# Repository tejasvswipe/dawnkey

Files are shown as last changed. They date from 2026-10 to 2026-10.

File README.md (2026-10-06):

# DAWNKEY — BLARE alarm clock

A custom BLARE alarm clock with a 12-key MX keypad, TFT display, DS3231 real-time clock, two-AA battery input and a distinctive printable case. The enclosure preview uses a black battery pod, dark display bezel and black **“for tejas”** lettering.
# gallery
preview_overall


## Deliverables

- **PCB source:** `PCB/DawnKey.kicad_pro`, routed `PCB/DawnKey.kicad_pcb`, placement-only backup, reproducible generator and the full BOM.
- **Fabrication:** `Production/Gerbers.zip` with copper, mask, silkscreen, board outline and separate plated/non-plated drill files; `Production/placements.csv` for assembly.
- **Enclosure:** OpenSCAD source, print-ready STLs and per-part/assembly STEP files under `CAD/`.
- **Firmware:** Arduino sketch and the key-by-key guide under `Firmware/`.
- **Build docs:** [power, wiring and button guide](Docs/Power_and_IO.md), [system block diagram](Docs/System_Architecture.png), sources, preview and preflight report.
 handoff, not a board ready to order or rely on as an alarm clock; complete full KiCad DRC, resolve the router discrepancy, inspect the boost layout and bench-test the assembled device first. The exact checks are in [`Production/Preflight.md`](Production/Preflight.md).

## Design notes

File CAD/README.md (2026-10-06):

# DAWNKEY case and print files

The case is a **parametric prototype** for the 94 × 90 mm PCB. The concept combines a dark raised TFT visor, 4 × 3 MX switch plate, buzzer vents, neon-style accent slots, a serviceable side battery pod and the black **“for tejas”** name insert.

## Files

- `DAWNKEY_Case.scad` — editable OpenSCAD master; change its `part` variable to render `base`, `top`, `bezel`, `battery_pod`, `battery_door`, `accents`, `text`, `key_labels` or the concept assembly.
- `STL/` — individual print-ready meshes; `key_labels.stl` and `text.stl` can be printed in black or inserted as separate color parts.
- `STEP/DAWNKEY_Case_Assembly.step` — positioned faceted case assembly; individual STEP files are alongside it. The STEP shapes were converted from STL meshes, so they are faceted rather than native analytic CAD solids.
- `STEP/DawnKey_PCB.step` — board-only STEP export.
- `stl_to_step.FCMacro` — reproducible FreeCAD STL-to-STEP export macro.

## Prototype geometry

The base/plate envelope is 108 × 132 mm. The side AA pod cavity is nominally 66 × 37 × 19 mm. The top plate has four M3 clearance openings, twelve nominal 14 mm MX apertures on 19.05 mm pitch, an ST7789 viewing aperture and a vent pattern over the piezo. The case is designed around common-size components; no actual TFT, AA holder, switch or heat-set insert has been test-fitted.

## Suggested assembly and print workflow

1. Render a small test of one MX opening, one M3 post and the display/bezel interface before printing all parts.
2. Print the base, top plate, visor, battery pod and door as separate pieces. Use the accent, wordmark and key-label meshes for a second color; the intended look is a light shell with black lettering/trim and a dark battery pod/visor.
3. Test the purchased 2-AA holder in the pod and measure its switch/harness. Adjust `DAWNKEY_Case.scad` if its actual dimensions differ from the nominal cavity.
4. Fit the TFT with the real panel PCB/cable; confirm the USB-C access slot and all four M3 inserts before final assembly.
5. Only then use the print-ready files for a full case.

The case render is a design visualization, **not proof of fit**. Check tolerances against your printer, filament shrinkage and actual parts.

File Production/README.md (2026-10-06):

# PCB production outputs

`Gerbers.zip` is the standard two-layer fabrication package. It contains the front/back copper, solder-mask and silkscreen layers, the Edge.Cuts outline, the Excellon plated (`PTH`) and non-plated (`NPTH`) drill files, KiCad’s Gerber job file, and SVG drill maps. Drill coordinates are in millimeters with absolute origin.

`placements.csv` is the component placement export for assembly. `pad_net_map.csv` is the component pad/net reference for review.

The board outline is nominally 94 × 90 mm with four M3-clearance holes. Before placing a manufacturing order, inspect the archive in the chosen fab’s Gerber viewer and confirm the material/thickness, copper weight, finish, tolerances, drill registration, and component clearances with that fab. The design has not been fabricated or electrically bench-tested; see `Preflight.md`. The native KiCad DRC is still required before manufacture.

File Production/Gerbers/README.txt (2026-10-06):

DAWNKEY PCB fabrication outputs

Board: nominal 94 x 90 mm, two copper layers.
Copper: DawnKey-F_Cu.gtl (front), DawnKey-B_Cu.gbl (back).
Mask: DawnKey-F_Mask.gts (front), DawnKey-B_Mask.gbs (back).
Silkscreen: DawnKey-F_Silkscreen.gto (front), DawnKey-B_Silkscreen.gbo (back).
Outline: DawnKey-Edge_Cuts.gm1.
Drills: DawnKey-PTH.drl (plated) and DawnKey-NPTH.drl (non-plated), Excellon, millimeters, absolute origin.

Review every layer and drill file in the board house's Gerber viewer before ordering. Material, copper weight, finish and tolerances are not prescribed here. See the project-level Production/Preflight.md: the design remains a prototype pending full KiCad DRC and resolution of a KiCad/FreeRouting round-trip discrepancy.

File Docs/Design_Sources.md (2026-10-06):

# Design sources and constraints

- BLARE Getting Started: https://blare.hackclub.com/docs/getting-started — kit includes XIAO ESP32-C3, 12 MX switches/keycaps, 12 1N4148 diodes, 2.25-inch TFT, 3.3 V piezo, display header/jumpers, and M3 case hardware.
- BLARE PCB guide: https://blare.hackclub.com/docs/pcb-design — KiCad `.kicad_pro`, `.kicad_sch`, `.kicad_pcb`, Gerber/Drill ZIP, and PCB STEP export; board under 100 mm per side.
- BLARE CAD guide: https://blare.hackclub.com/docs/cad — complete assembled STEP; separate case parts STEP or STL; switch, screen, USB and buzzer openings; M3 inserts/posts; leave at least 0.2 mm fit tolerance.
- BLARE submission guide: https://blare.hackclub.com/docs/submitting-your-project — folders `CAD`, `PCB`, `Firmware`, `Production`; `Production/gerbers.zip`; README screenshots for overall build, schematic, PCB, and case fit, plus BOM; DRC should show zero errors.
- BLARE firmware guide: https://blare.hackclub.com/docs/firmware — ST7789 panel is 76×284; display can use the documented XIAO GPIO mapping; active-low backlight.
- Seeed XIAO ESP32-C3 official hardware guide: https://wiki.seeedstudio.com/XIAO_ESP32C3_Getting_Started/ — 5V/VBUS is a power input/output; external supply must feed it through a diode with anode at source and cathode at XIAO 5V. The 3V3 pin is regulator output, not the battery input. Seeed documents 3.7 V lithium-battery input, not direct 2×AA input.
- Texas Instruments TPS61023 datasheet: https://www.ti.com/lit/ds/symlink/tps61023.pdf — 0.5–5.5 V operating input; 1.8 V minimum startup; 2.2–5.5 V output; typical 5 V/1.5 A design is specified at 2.7–4.35 V input. For 2×AA, output current must be validated at depleted-cell voltage and actual clock load; do not assume 1.5 A at 1.8 V.
- TI TPS61022/TPS61023 layout guidelines: https://www.ti.com/lit/pdf/slvaes4 — keep the switching/current loop and output capacitors tight; route feedback away from noisy SW node.

## Battery safety/design note

A two-cell AA series pack spans roughly 1.8 V at end-of-life to about 3.3 V fresh (cell chemistry dependent). A regulated boost stage is required for the XIAO 5V pin; use an output isolation Schottky diode per Seeed. There is no onboard AA charging. Do not place raw AA voltage on XIAO 3V3 or 5V. Wi-Fi, bright TFT backlight, and buzzer duty cycle determine battery life; measure on the finished firmware/load before quoting runtime.

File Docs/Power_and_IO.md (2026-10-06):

# DAWNKEY power, wiring and controls

## 1. Two-AA power path

Use a **two-cell AA holder wired in series** with a 2-pin JST-PH lead. The PCB connector is `J3`:

| J3 pin | PCB net | Connect to |
|---|---|---|
| 1 | `BAT_RAW` | Positive from the battery holder, through an inline SPST on/off switch |
| 2 | `GND` | Battery-holder negative |

The board uses a **TPS61023 boost converter** to make a regulated nominal 5 V rail (`BOOST_5V`). Its output reaches the Seeed XIAO ESP32-C3 5V pad through **D13, an SS14 Schottky diode**. The diode is oriented with its anode at `BOOST_5V` and cathode at `USB_5V` / the XIAO 5V pad. The XIAO’s onboard regulator then supplies the 3.3 V rail used by the RTC, GPIO expander, display logic and buzzer.

**Important:** raw AA voltage must never be connected directly to the XIAO 3V3 pin or directly to its 5V pin. The cells are primary power sources; the PCB does **not** charge NiMH cells. Use a matched pair of the same chemistry and state of charge. Before inserting cells, check polarity, inspect U4/L1/D13 orientation, and measure the boosted output and the diode-side XIAO input with a current-limited bench supply. Test USB-versus-battery behavior on the bench; do not assume it is safe until verified on the assembled board.

The DS3231 `VBAT` pin is tied to ground because the AA pack is intended to remain the clock’s always-on supply. **If the AA pack is removed, the RTC time will be lost** (the firmware initializes the date/time from its compile timestamp at next start). This design has no separate coin-cell backup.

## 2. Signal and connector map

### XIAO ESP32-C3

| XIAO Arduino pin | Role | Routed net |
|---|---|---|
| D0 | TFT SCLK | `TFT_SCLK` |
| D1 | TFT MOSI | `TFT_MOSI` |
| D2 | TFT reset | `TFT_RST` |
| D3 | TFT data/command | `TFT_DC` |
| D4 | TFT chip select | `TFT_CS` |
| D5 | TFT backlight enable | `TFT_BL` (active-low on the BLARE panel) |
| D6 | I²C clock | `I2C_SCL` |
| D7 | I²C data | `I2C_SDA` |
| D10 | Piezo driver control | `BUZZER_CTL` |
| 5V | Boost/USB input | `USB_5V` through D13 from battery boost |
| 3V3 | Regulated output | `3V3` |
| GND | Common return | `GND` |

GPIO8/GPIO9 are deliberately left unused because of ESP32-C3 boot-strapping considerations.

### TFT header J1

The 8-pin BLARE/ST7789 header order is **GND, 3V3, SCLK, MOSI, RST, DC, CS, BL**. The display is an external module connected with the kit jumper wires; it is not soldered flat to the PCB.

### I²C devices and expansion J2

- U2 MCP23017: address `0x20`; GPIO expander for the keypad.
- U3 DS3231: address `0x68`; clock/alarm time source.
- Pull-ups R4/R5: 4.7 kΩ from SDA/SCL to 3V3.
- J2 pins 1–4: **3V3, GND, SDA, SCL**. This is a low-current sensor/accessory header, not a general-purpose power output.

R3–R5 are non-polar 0603 resistors. Their PCB pad numbering is intentionally exchanged to compensate for the underside autorouter/import transform; electrically, each resistor still connects the signal named in the BOM to 3V3. There is no physical resistor polarity or orientation requirement.

### Key matrix

U2 GPA0–GPA3 are columns 0–3; GPA4–GPA6 are rows 0–2. One 1N4148 diode is fitted per MX-style switch to prevent matrix ghosting. The diode direction is from each row toward its switch/column node as shown by the PCB net assignments.

## 3. Every button

Viewed from the front with the display above the keypad, read left-to-right and top-to-bottom:

| Position / label | Normal clock screen | While setting time/alarm | While ringing |
|---|---|---|---|
| Top row: `1`, `2`, `3`, `4` | No action | Enters that digit | Enters that digit into the dismiss code |
| Middle row: `5`, `6`, `7`, `8` | No action | Enters that digit | Enters that digit into the dismiss code |
| Bottom-left: `9` | No action | Enters 9 | Enters 9 into the dismiss code |
| Bottom, second: `0` | No action | Enters 0 | Enters 0 into the dismiss code |
| Bottom, third: `S` / Snooze (SW11) | Short press changes the display page; hold about 0.85 s to set the RTC clock | Short press clears the typed entry | Short press silences the buzzer and snoozes for 5 minutes |
| Bottom-right: `OK` / Stop (SW12) | Short press toggles the alarm on/off; hold about 0.85 s to set the alarm time | Saves a valid four-digit `HHMM` value | Stops only after the four-digit code is entered and confirmed |

The starter firmware’s example dismiss code is **3141**. While ringing, type the four digits with keys 1–0 and press `OK`. A wrong code clears the entry but leaves the alarm active. The default alarm is **07:00 and enabled**. In either setting mode, enter 24-hour `HHMM` using the number keys; invalid hour/minute values are rejected.

## 4. Bring-up checklist

1. Assemble the board without batteries. Inspect solder bridges, polarity, connector pin order, U4, L1 and D13.
2. Power through a current-limited bench supply at J3. Confirm the boost and diode-side rail before attaching the XIAO or display.
3. Scan I²C: expect MCP23017 `0x20` and DS3231 `0x68`.
4. Verify the display pin order/backlight polarity and test every matrix key individually.
5. Confirm buzzer switching, RTC time setting, alarm setting, snooze, wake-code dismissal, and both USB/battery source modes.
6. Measure battery current and runtime with the actual TFT backlight and alarm duty cycle. Runtime has not yet been measured; the starter sketch keeps the backlight on.

This is a prototype package. No physical board has been fabricated or bench-tested here; inspect the KiCad DRC report and verify current, voltage, thermal behavior and mechanical fit before relying on it as a daily alarm.

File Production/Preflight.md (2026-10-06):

# Release preflight and limits

## Checks performed on this release

- **KiCad native connectivity API:** the imported `PCB/DawnKey.kicad_pcb` reports **0 unconnected connections** (`GetUnconnectedCount(True) = 0`).
- **FreeRouting 2.5 on the placement-only KiCad export:** `PCB/route.log` reports **0 unrouted connections and 0 clearance violations** (score 1000/1000). `PCB/DawnKey.ses` is the resulting routing session.
- **Gerber/drill/position exports:** produced with KiCad CLI 7 from the routed board; PTH and NPTH drills are separate, in mm, absolute origin.
- **Case CAD:** OpenSCAD produced the STL parts; FreeCAD reported all eight meshes as valid and exported the individual and positioned assembly STEP files.

## Important unresolved discrepancy

I also exported a fresh Specctra DSN from the **imported final `.kicad_pcb`** and re-ran FreeRouting on that round-tripped board. KiCad still reported 0 unconnected connections, but FreeRouting reported **5 unrouted items and 0 clearance violations**. This disagreement is not resolved. The placement-board router result and the KiCad connectivity graph are encouraging, but they do not prove that every imported copper endpoint is interpreted identically by both tools.

## Required before fabrication or daily use

1. Open the final project in a current KiCad version, run the full native **DRC**, inspect the ratsnest and inspect the buzzer, underside pull-ups, battery boost and display connections.
2. Review the Gerbers in the intended board house’s viewer.
3. Verify the actual TFT, 2-AA holder, MX switches, heat-set inserts and case clearances with physical components; the enclosure has not been test-fitted.
4. The Arduino toolchain/libraries were not available here, so the firmware was **not compiled or uploaded**. Compile for the Seeed XIAO ESP32-C3 and test every mode before assembly use.
5. No physical PCB has been fabricated or bench-tested. Check the 5 V/3.3 V rails with a current-limited supply before installing cells; do not rely on this prototype as a tested alarm clock yet.

The installed KiCad 7 command-line interface does not provide `kicad-cli pcb drc`; therefore no full KiCad DRC result is claimed. Treat this package as a complete design handoff/prototype, **not as a certified or production-released board**.

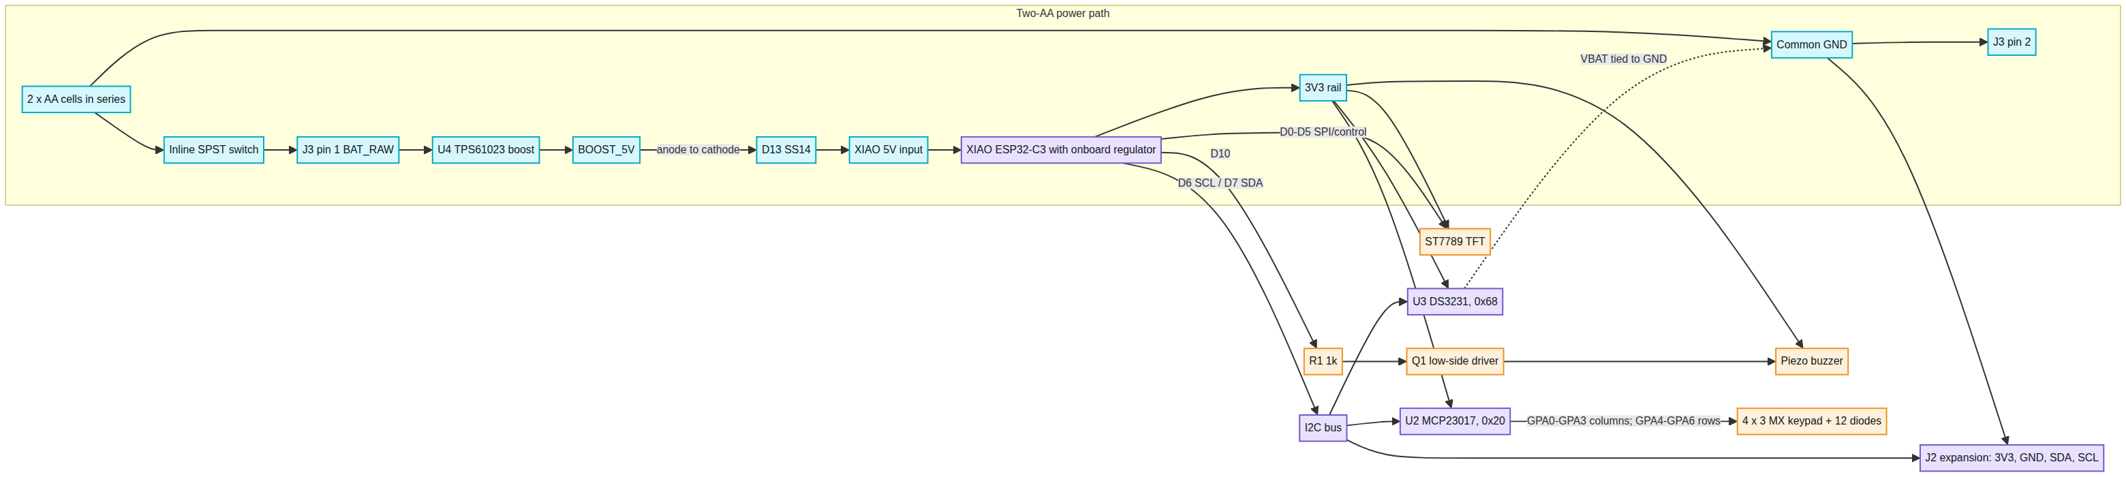
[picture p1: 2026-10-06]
Docs/System_Architecture.png

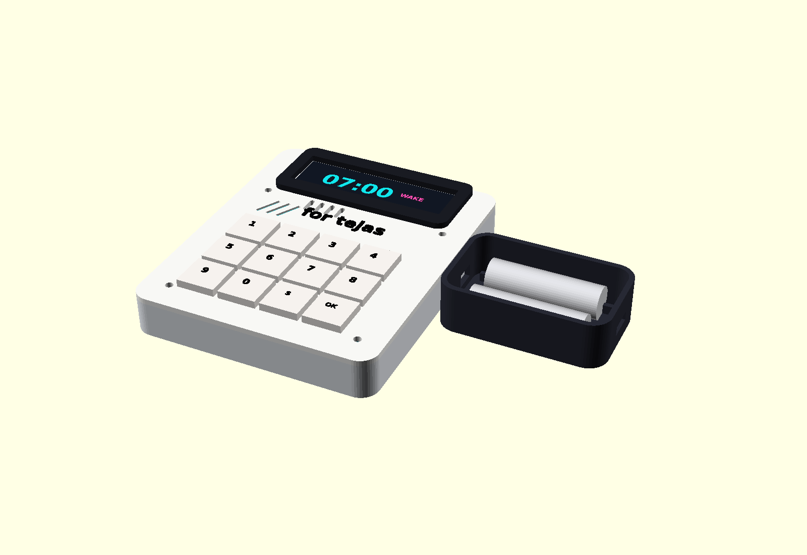
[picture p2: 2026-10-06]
Docs/preview_overall.png

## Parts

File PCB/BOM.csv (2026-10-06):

Reference | Qty | Description | Recommended part/value | Package / interface | Notes
U1 | 1 | MCU module | Seeed XIAO ESP32-C3 | Module | Kit part; mount on underside per board footprint
U2 | 1 | I2C GPIO expander | MCP23017-I/SO | SOIC-28W | Address 0x20; keypad matrix
U3 | 1 | RTC | DS3231S | SOIC-16W | Address 0x68; unused VBAT tied to GND
U4 | 1 | AA boost converter | TI TPS61023DRLR or equivalent TPS61023 SOT-563 | 6-pin SOT-563 | Check exact package variant/pin-1 mark against datasheet
L1 | 1 | Boost inductor | Würth 74438357010 1uH | 4.1x4.1mm shielded | Select >=7A saturation current; follow TI layout guidance
D13 | 1 | 5V isolation diode | SS14 Schottky | DO-214AC / SMA | Pad 2 anode=boost; pad 1 cathode=XIAO 5V
C3 | 1 | Boost input capacitor | 10uF 10V X7R | 0805 | Place tight to U4 VIN/GND
C4 | 1 | High-frequency input bypass | 100nF X7R | 0603 | Place tight to U4 VIN/GND
C5-C6 | 2 | Boost output capacitors | 22uF 10V X7R | 0805 | Parallel; check effective capacitance under DC bias
R6 | 1 | Feedback upper resistor | 732k 1% | 0603 | BOOST_5V to FB
R7 | 1 | Feedback lower resistor | 100k 1% | 0603 | FB to GND
DISP1 | 1 | Display module | 2.25in ST7789 76x284 panel | 8-pin jumper cable | Kit item; VCC=3V3; BL active-low
J1 | 1 | TFT connector | 1x8 2.54mm pin header | Through-hole | BLARE kit order: GND | 3V3 | SCLK | MOSI | RST | DC | CS | BL
J2 | 1 | I2C expansion | 1x4 2.54mm header | Through-hole | 3V3/GND/SDA/SCL
J3 | 1 | 2-cell battery input | JST-PH 2-pin 2.0mm | Side-entry connector | Two AA in series; switched battery-positive input
BT1 | 1 | AA holder | 2-cell AA series holder with JST-PH lead | External case pocket | Alkaline or NiMH pair; no charging circuit on PCB
SW-PWR | 1 | Power switch | SPST slide switch rated >=1A | Inline on AA positive lead | Panel slot in battery pod; confirm switch body dimensions
SW01-SW12 | 12 | MX-style mechanical switches | BLARE kit switches | Plate-mount | 4 columns x 3 rows; 19.05mm pitch
D01-D12 | 12 | Signal diodes | 1N4148 | DO-35 axial | One per key; matrix direction per PCB
BZ1 | 1 | Piezo buzzer | 3.3V piezo | 12mm / 7.6mm lead pitch | Kit item; driven by Q1
Q1 | 1 | Buzzer NPN transistor | MMBT3904 | SOT-23 | Low-side switch; confirm package pinout
R1 | 1 | Buzzer base resistor | 1k | 0603 | GPIO-to-base
R2 | 1 | RTC interrupt pull-up | 10k | 0603 | RTC_INT net currently unused by starter code
R3 | 1 | MCP reset pull-up | 10k | 0603 | RESET to 3V3
R4-R5 | 2 | I2C pull-ups | 4.7k | 0603 | SDA and SCL to 3V3
C1-C2 | 2 | Logic decoupling | 100nF X7R | 0603 | One each for MCP23017 and DS3231
H1-H4 | 4 | PCB mounting holes | M3 clearance | 3.2mm NPTH | Match case supports/heat-set inserts
CASE | 1 | Enclosure set | Top plate | bottom shell | display bezel | battery pod and door | 3D printed | See CAD folder; verify exact display/holder and switch sizes before printing

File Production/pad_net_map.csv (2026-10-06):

Reference | Value | Pad | Net | X_mm | Y_mm | Side
BZ1 | 3.3V PIEZO | 1 | 3V3 | 28.200 | 74.000 | B.Cu
BZ1 | 3.3V PIEZO | 2 | BUZZER | 35.800 | 74.000 | B.Cu
C1 | 100nF MCP DECOUPLE | 1 | 3V3 | 56.300 | 74.700 | B.Cu
C1 | 100nF MCP DECOUPLE | 2 | GND | 56.300 | 76.300 | B.Cu
C2 | 100nF RTC DECOUPLE | 1 | 3V3 | 70.500 | 70.000 | B.Cu
C2 | 100nF RTC DECOUPLE | 2 | GND | 70.500 | 71.600 | B.Cu
C3 | 10uF 10V X7R IN | 1 | BAT_RAW | 79.450 | 68.500 | B.Cu
C3 | 10uF 10V X7R IN | 2 | GND | 77.550 | 68.500 | B.Cu
C4 | 100nF BOOST HF | 1 | BAT_RAW | 77.700 | 72.000 | B.Cu
C4 | 100nF BOOST HF | 2 | GND | 79.300 | 72.000 | B.Cu
C5 | 22uF 10V X7R OUT | 1 | BOOST_5V | 87.950 | 75.500 | B.Cu
C5 | 22uF 10V X7R OUT | 2 | GND | 86.050 | 75.500 | B.Cu
C6 | 22uF 10V X7R OUT | 1 | BOOST_5V | 90.950 | 79.000 | B.Cu
C6 | 22uF 10V X7R OUT | 2 | GND | 89.050 | 79.000 | B.Cu
D01 | 1N4148 / DO-35 | 1 | KINT01 | 21.425 | 46.520 | B.Cu
D01 | 1N4148 / DO-35 | 2 | KEY_ROW0 | 29.045 | 46.520 | B.Cu
D02 | 1N4148 / DO-35 | 1 | KINT02 | 40.475 | 46.520 | B.Cu
D02 | 1N4148 / DO-35 | 2 | KEY_ROW0 | 48.095 | 46.520 | B.Cu
D03 | 1N4148 / DO-35 | 1 | KINT03 | 59.525 | 46.520 | B.Cu
D03 | 1N4148 / DO-35 | 2 | KEY_ROW0 | 67.145 | 46.520 | B.Cu
D04 | 1N4148 / DO-35 | 1 | KINT04 | 78.575 | 46.520 | B.Cu
D04 | 1N4148 / DO-35 | 2 | KEY_ROW0 | 86.195 | 46.520 | B.Cu
D05 | 1N4148 / DO-35 | 1 | KINT05 | 21.425 | 27.470 | B.Cu
D05 | 1N4148 / DO-35 | 2 | KEY_ROW1 | 29.045 | 27.470 | B.Cu
D06 | 1N4148 / DO-35 | 1 | KINT06 | 40.475 | 27.470 | B.Cu
D06 | 1N4148 / DO-35 | 2 | KEY_ROW1 | 48.095 | 27.470 | B.Cu
D07 | 1N4148 / DO-35 | 1 | KINT07 | 59.525 | 27.470 | B.Cu
D07 | 1N4148 / DO-35 | 2 | KEY_ROW1 | 67.145 | 27.470 | B.Cu
D08 | 1N4148 / DO-35 | 1 | KINT08 | 78.575 | 27.470 | B.Cu
D08 | 1N4148 / DO-35 | 2 | KEY_ROW1 | 86.195 | 27.470 | B.Cu
D09 | 1N4148 / DO-35 | 1 | KINT09 | 21.425 | 8.420 | B.Cu
D09 | 1N4148 / DO-35 | 2 | KEY_ROW2 | 29.045 | 8.420 | B.Cu
D10 | 1N4148 / DO-35 | 1 | KINT10 | 40.475 | 8.420 | B.Cu
D10 | 1N4148 / DO-35 | 2 | KEY_ROW2 | 48.095 | 8.420 | B.Cu
D11 | 1N4148 / DO-35 | 1 | KINT11 | 59.525 | 8.420 | B.Cu
D11 | 1N4148 / DO-35 | 2 | KEY_ROW2 | 67.145 | 8.420 | B.Cu
D12 | 1N4148 / DO-35 | 1 | KINT12 | 78.575 | 8.420 | B.Cu
D12 | 1N4148 / DO-35 | 2 | KEY_ROW2 | 86.195 | 8.420 | B.Cu
D13 | SS14 1A SCHOTTKY | 1 | USB_5V | 80.500 | 78.000 | B.Cu
D13 | SS14 1A SCHOTTKY | 2 | BOOST_5V | 76.500 | 78.000 | B.Cu
H1 | M3 CLEARANCE |  |  | 4.500 | 4.500 | F.Cu
H2 | M3 CLEARANCE |  |  | 89.500 | 4.500 | F.Cu
H3 | M3 CLEARANCE |  |  | 4.500 | 85.500 | F.Cu
H4 | M3 CLEARANCE |  |  | 89.500 | 85.500 | F.Cu
J1 | TFT / ST7789 | 1 | GND | 90.500 | 22.000 | F.Cu
J1 | TFT / ST7789 | 2 | 3V3 | 90.500 | 24.540 | F.Cu
J1 | TFT / ST7789 | 3 | TFT_SCLK | 90.500 | 27.080 | F.Cu
J1 | TFT / ST7789 | 4 | TFT_MOSI | 90.500 | 29.620 | F.Cu
J1 | TFT / ST7789 | 5 | TFT_RST | 90.500 | 32.160 | F.Cu
J1 | TFT / ST7789 | 6 | TFT_DC | 90.500 | 34.700 | F.Cu
J1 | TFT / ST7789 | 7 | TFT_CS | 90.500 | 37.240 | F.Cu
J1 | TFT / ST7789 | 8 | TFT_BL | 90.500 | 39.780 | F.Cu
J2 | I2C EXPANSION: 3V3 GND SDA SCL | 1 | 3V3 | 39.000 | 64.000 | B.Cu
J2 | I2C EXPANSION: 3V3 GND SDA SCL | 2 | GND | 39.000 | 66.540 | B.Cu
J2 | I2C EXPANSION: 3V3 GND SDA SCL | 3 | I2C_SDA | 39.000 | 69.080 | B.Cu
J2 | I2C EXPANSION: 3V3 GND SDA SCL | 4 | I2C_SCL | 39.000 | 71.620 | B.Cu
J3 | 2xAA PACK (SWITCHED) | 1 | BAT_RAW | 76.000 | 86.000 | B.Cu
J3 | 2xAA PACK (SWITCHED) | 2 | GND | 74.000 | 86.000 | B.Cu
L1 | 1uH Isat>=7A | 1 | BAT_RAW | 88.685 | 69.000 | B.Cu
L1 | 1uH Isat>=7A | 2 | BOOST_SW | 86.315 | 69.000 | B.Cu
Q1 | MMBT3904 / NPN | 1 | BUZZER_SW | 41.438 | 76.050 | B.Cu
Q1 | MMBT3904 / NPN | 2 | GND | 41.438 | 77.950 | B.Cu
Q1 | MMBT3904 / NPN | 3 | BUZZER | 39.562 | 77.000 | B.Cu
R1 | 1k BUZZER BASE | 1 | BUZZER_CTL | 31.200 | 65.500 | F.Cu
R1 | 1k BUZZER BASE | 2 | BUZZER_SW | 32.800 | 65.500 | F.Cu
R2 | 10k RTC INT PU | 1 | RTC_INT | 56.200 | 65.500 | B.Cu
R2 | 10k RTC INT PU | 2 | 3V3 | 57.800 | 65.500 | B.Cu
R3 | 10k MCP RESET PU | 1 | 3V3 | 51.000 | 63.700 | B.Cu
R3 | 10k MCP RESET PU | 2 | MCP_RESET | 51.000 | 65.300 | B.Cu
R4 | 4k7 I2C SDA PU | 1 | 3V3 | 59.000 | 63.700 | B.Cu
R4 | 4k7 I2C SDA PU | 2 | I2C_SDA | 59.000 | 65.300 | B.Cu
R5 | 4k7 I2C SCL PU | 1 | 3V3 | 64.000 | 63.700 | B.Cu
R5 | 4k7 I2C SCL PU | 2 | I2C_SCL | 64.000 | 65.300 | B.Cu
R6 | 732k BOOST FB TOP | 1 | BOOST_5V | 83.200 | 82.000 | B.Cu
R6 | 732k BOOST FB TOP | 2 | BOOST_FB | 84.800 | 82.000 | B.Cu
R7 | 100k BOOST FB BOT | 1 | BOOST_FB | 86.700 | 82.000 | B.Cu
R7 | 100k BOOST FB BOT | 2 | GND | 88.300 | 82.000 | B.Cu
SW01 | MX-STYLE KEY 01 | 1 | KEY_COL0 | 12.615 | 49.060 | F.Cu
SW01 | MX-STYLE KEY 01 | 2 | KINT01 | 18.965 | 46.520 | F.Cu
SW01 | MX-STYLE KEY 01 |  |  | 11.345 | 51.600 | F.Cu
SW01 | MX-STYLE KEY 01 |  |  | 16.425 | 51.600 | F.Cu
SW01 | MX-STYLE KEY 01 |  |  | 21.505 | 51.600 | F.Cu
SW02 | MX-STYLE KEY 02 | 1 | KEY_COL1 | 31.665 | 49.060 | F.Cu
SW02 | MX-STYLE KEY 02 | 2 | KINT02 | 38.015 | 46.520 | F.Cu
SW02 | MX-STYLE KEY 02 |  |  | 30.395 | 51.600 | F.Cu
SW02 | MX-STYLE KEY 02 |  |  | 35.475 | 51.600 | F.Cu
SW02 | MX-STYLE KEY 02 |  |  | 40.555 | 51.600 | F.Cu
SW03 | MX-STYLE KEY 03 | 1 | KEY_COL2 | 50.715 | 49.060 | F.Cu
SW03 | MX-STYLE KEY 03 | 2 | KINT03 | 57.065 | 46.520 | F.Cu
SW03 | MX-STYLE KEY 03 |  |  | 49.445 | 51.600 | F.Cu
SW03 | MX-STYLE KEY 03 |  |  | 54.525 | 51.600 | F.Cu
SW03 | MX-STYLE KEY 03 |  |  | 59.605 | 51.600 | F.Cu
SW04 | MX-STYLE KEY 04 | 1 | KEY_COL3 | 69.765 | 49.060 | F.Cu
SW04 | MX-STYLE KEY 04 | 2 | KINT04 | 76.115 | 46.520 | F.Cu
SW04 | MX-STYLE KEY 04 |  |  | 68.495 | 51.600 | F.Cu
SW04 | MX-STYLE KEY 04 |  |  | 73.575 | 51.600 | F.Cu
SW04 | MX-STYLE KEY 04 |  |  | 78.655 | 51.600 | F.Cu
SW05 | MX-STYLE KEY 05 | 1 | KEY_COL0 | 12.615 | 30.010 | F.Cu
SW05 | MX-STYLE KEY 05 | 2 | KINT05 | 18.965 | 27.470 | F.Cu
SW05 | MX-STYLE KEY 05 |  |  | 11.345 | 32.550 | F.Cu
SW05 | MX-STYLE KEY 05 |  |  | 16.425 | 32.550 | F.Cu
SW05 | MX-STYLE KEY 05 |  |  | 21.505 | 32.550 | F.Cu
SW06 | MX-STYLE KEY 06 | 1 | KEY_COL1 | 31.665 | 30.010 | F.Cu
SW06 | MX-STYLE KEY 06 | 2 | KINT06 | 38.015 | 27.470 | F.Cu
SW06 | MX-STYLE KEY 06 |  |  | 30.395 | 32.550 | F.Cu
SW06 | MX-STYLE KEY 06 |  |  | 35.475 | 32.550 | F.Cu
SW06 | MX-STYLE KEY 06 |  |  | 40.555 | 32.550 | F.Cu
SW07 | MX-STYLE KEY 07 | 1 | KEY_COL2 | 50.715 | 30.010 | F.Cu
SW07 | MX-STYLE KEY 07 | 2 | KINT07 | 57.065 | 27.470 | F.Cu
SW07 | MX-STYLE KEY 07 |  |  | 49.445 | 32.550 | F.Cu
SW07 | MX-STYLE KEY 07 |  |  | 54.525 | 32.550 | F.Cu
SW07 | MX-STYLE KEY 07 |  |  | 59.605 | 32.550 | F.Cu
SW08 | MX-STYLE KEY 08 | 1 | KEY_COL3 | 69.765 | 30.010 | F.Cu
SW08 | MX-STYLE KEY 08 | 2 | KINT08 | 76.115 | 27.470 | F.Cu
SW08 | MX-STYLE KEY 08 |  |  | 68.495 | 32.550 | F.Cu
SW08 | MX-STYLE KEY 08 |  |  | 73.575 | 32.550 | F.Cu
SW08 | MX-STYLE KEY 08 |  |  | 78.655 | 32.550 | F.Cu
SW09 | MX-STYLE KEY 09 | 1 | KEY_COL0 | 12.615 | 10.960 | F.Cu
SW09 | MX-STYLE KEY 09 | 2 | KINT09 | 18.965 | 8.420 | F.Cu
SW09 | MX-STYLE KEY 09 |  |  | 11.345 | 13.500 | F.Cu
SW09 | MX-STYLE KEY 09 |  |  | 16.425 | 13.500 | F.Cu
SW09 | MX-STYLE KEY 09 |  |  | 21.505 | 13.500 | F.Cu
SW10 | MX-STYLE KEY 10 | 1 | KEY_COL1 | 31.665 | 10.960 | F.Cu
SW10 | MX-STYLE KEY 10 | 2 | KINT10 | 38.015 | 8.420 | F.Cu
SW10 | MX-STYLE KEY 10 |  |  | 30.395 | 13.500 | F.Cu
SW10 | MX-STYLE KEY 10 |  |  | 35.475 | 13.500 | F.Cu
SW10 | MX-STYLE KEY 10 |  |  | 40.555 | 13.500 | F.Cu
SW11 | MX-STYLE KEY 11 | 1 | KEY_COL2 | 50.715 | 10.960 | F.Cu
SW11 | MX-STYLE KEY 11 | 2 | KINT11 | 57.065 | 8.420 | F.Cu
SW11 | MX-STYLE KEY 11 |  |  | 49.445 | 13.500 | F.Cu
SW11 | MX-STYLE KEY 11 |  |  | 54.525 | 13.500 | F.Cu
SW11 | MX-STYLE KEY 11 |  |  | 59.605 | 13.500 | F.Cu
SW12 | MX-STYLE KEY 12 | 1 | KEY_COL3 | 69.765 | 10.960 | F.Cu
SW12 | MX-STYLE KEY 12 | 2 | KINT12 | 76.115 | 8.420 | F.Cu
SW12 | MX-STYLE KEY 12 |  |  | 68.495 | 13.500 | F.Cu
SW12 | MX-STYLE KEY 12 |  |  | 73.575 | 13.500 | F.Cu
SW12 | MX-STYLE KEY 12 |  |  | 78.655 | 13.500 | F.Cu
U1 | XIAO ESP32-C3 | 1 | TFT_SCLK | 9.380 | 79.620 | B.Cu
U1 | XIAO ESP32-C3 | 2 | TFT_MOSI | 9.380 | 77.080 | B.Cu
U1 | XIAO ESP32-C3 | 3 | TFT_RST | 9.380 | 74.540 | B.Cu
U1 | XIAO ESP32-C3 | 4 | TFT_DC | 9.380 | 72.000 | B.Cu
U1 | XIAO ESP32-C3 | 5 | TFT_CS | 9.380 | 69.460 | B.Cu
U1 | XIAO ESP32-C3 | 6 | TFT_BL | 9.380 | 66.920 | B.Cu
U1 | XIAO ESP32-C3 | 7 | I2C_SCL | 9.380 | 64.380 | B.Cu
U1 | XIAO ESP32-C3 | 8 | I2C_SDA | 24.620 | 64.380 | B.Cu
U1 | XIAO ESP32-C3 | 9 |  | 24.620 | 66.920 | B.Cu
U1 | XIAO ESP32-C3 | 10 |  | 24.620 | 69.460 | B.Cu
U1 | XIAO ESP32-C3 | 11 | BUZZER_CTL | 24.620 | 72.000 | B.Cu
U1 | XIAO ESP32-C3 | 12 | 3V3 | 24.620 | 74.540 | B.Cu
U1 | XIAO ESP32-C3 | 13 | GND | 24.620 | 77.080 | B.Cu
U1 | XIAO ESP32-C3 | 14 | USB_5V | 24.620 | 79.620 | B.Cu
U2 | MCP23017-I/SO | 1 | KEY_COL0 | 54.150 | 64.745 | B.Cu
U2 | MCP23017-I/SO | 2 | KEY_COL1 | 54.150 | 66.015 | B.Cu
U2 | MCP23017-I/SO | 3 | KEY_COL2 | 54.150 | 67.285 | B.Cu
U2 | MCP23017-I/SO | 4 | KEY_COL3 | 54.150 | 68.555 | B.Cu
U2 | MCP23017-I/SO | 5 | KEY_ROW0 | 54.150 | 69.825 | B.Cu
U2 | MCP23017-I/SO | 6 | KEY_ROW1 | 54.150 | 71.095 | B.Cu
U2 | MCP23017-I/SO | 7 | KEY_ROW2 | 54.150 | 72.365 | B.Cu
U2 | MCP23017-I/SO | 8 |  | 54.150 | 73.635 | B.Cu
U2 | MCP23017-I/SO | 9 | 3V3 | 54.150 | 74.905 | B.Cu
U2 | MCP23017-I/SO | 10 | GND | 54.150 | 76.175 | B.Cu
U2 | MCP23017-I/SO | 11 |  | 54.150 | 77.445 | B.Cu
U2 | MCP23017-I/SO | 12 | I2C_SCL | 54.150 | 78.715 | B.Cu
U2 | MCP23017-I/SO | 13 | I2C_SDA | 54.150 | 79.985 | B.Cu
U2 | MCP23017-I/SO | 14 |  | 54.150 | 81.255 | B.Cu
U2 | MCP23017-I/SO | 15 | GND | 44.850 | 81.255 | B.Cu
U2 | MCP23017-I/SO | 16 | GND | 44.850 | 79.985 | B.Cu
U2 | MCP23017-I/SO | 17 | GND | 44.850 | 78.715 | B.Cu
U2 | MCP23017-I/SO | 18 | MCP_RESET | 44.850 | 77.445 | B.Cu
U2 | MCP23017-I/SO | 19 |  | 44.850 | 76.175 | B.Cu
U2 | MCP23017-I/SO | 20 |  | 44.850 | 74.905 | B.Cu
U2 | MCP23017-I/SO | 21 |  | 44.850 | 73.635 | B.Cu
U2 | MCP23017-I/SO | 22 |  | 44.850 | 72.365 | B.Cu
U2 | MCP23017-I/SO | 23 |  | 44.850 | 71.095 | B.Cu
U2 | MCP23017-I/SO | 24 |  | 44.850 | 69.825 | B.Cu
U2 | MCP23017-I/SO | 25 |  | 44.850 | 68.555 | B.Cu
U2 | MCP23017-I/SO | 26 |  | 44.850 | 67.285 | B.Cu
U2 | MCP23017-I/SO | 27 |  | 44.850 | 66.015 | B.Cu
U2 | MCP23017-I/SO | 28 |  | 44.850 | 64.745 | B.Cu
U3 | DS3231S RTC | 1 |  | 68.650 | 68.555 | B.Cu
U3 | DS3231S RTC | 2 | 3V3 | 68.650 | 69.825 | B.Cu
U3 | DS3231S RTC | 3 | RTC_INT | 68.650 | 71.095 | B.Cu
U3 | DS3231S RTC | 4 |  | 68.650 | 72.365 | B.Cu
U3 | DS3231S RTC | 5 | GND | 68.650 | 73.635 | B.Cu
U3 | DS3231S RTC | 6 | GND | 68.650 | 74.905 | B.Cu
U3 | DS3231S RTC | 7 | GND | 68.650 | 76.175 | B.Cu
U3 | DS3231S RTC | 8 | GND | 68.650 | 77.445 | B.Cu
U3 | DS3231S RTC | 9 | GND | 59.350 | 77.445 | B.Cu
U3 | DS3231S RTC | 10 | GND | 59.350 | 76.175 | B.Cu
U3 | DS3231S RTC | 11 | GND | 59.350 | 74.905 | B.Cu
U3 | DS3231S RTC | 12 | GND | 59.350 | 73.635 | B.Cu
U3 | DS3231S RTC | 13 | GND | 59.350 | 72.365 | B.Cu
U3 | DS3231S RTC | 14 | GND | 59.350 | 71.095 | B.Cu
U3 | DS3231S RTC | 15 | I2C_SDA | 59.350 | 69.825 | B.Cu
U3 | DS3231S RTC | 16 | I2C_SCL | 59.350 | 68.555 | B.Cu
U4 | TPS61023 2xAA BOOST | 1 | BOOST_FB | 82.750 | 71.500 | B.Cu
U4 | TPS61023 2xAA BOOST | 2 | BAT_RAW | 82.750 | 72.000 | B.Cu
U4 | TPS61023 2xAA BOOST | 3 | BAT_RAW | 82.750 | 72.500 | B.Cu
U4 | TPS61023 2xAA BOOST | 4 | GND | 81.250 | 72.500 | B.Cu
U4 | TPS61023 2xAA BOOST | 5 | BOOST_SW | 81.250 | 72.000 | B.Cu
U4 | TPS61023 2xAA BOOST | 6 | BOOST_5V | 81.250 | 71.500 | B.Cu

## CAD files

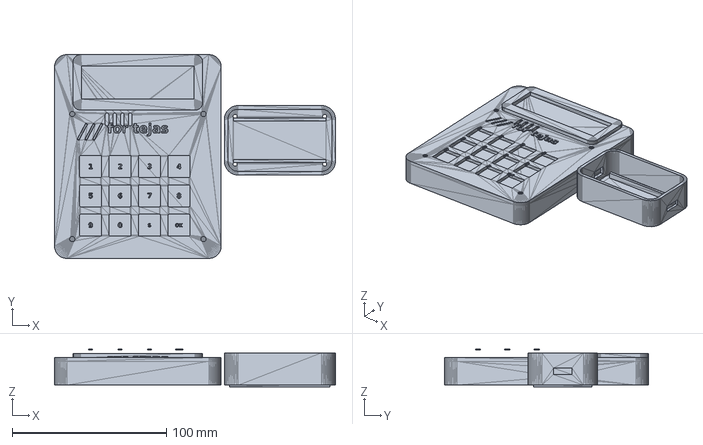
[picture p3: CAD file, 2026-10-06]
CAD/STEP/DAWNKEY_Case_Assembly.step
182.0 x 132.0 x 24.3 mm

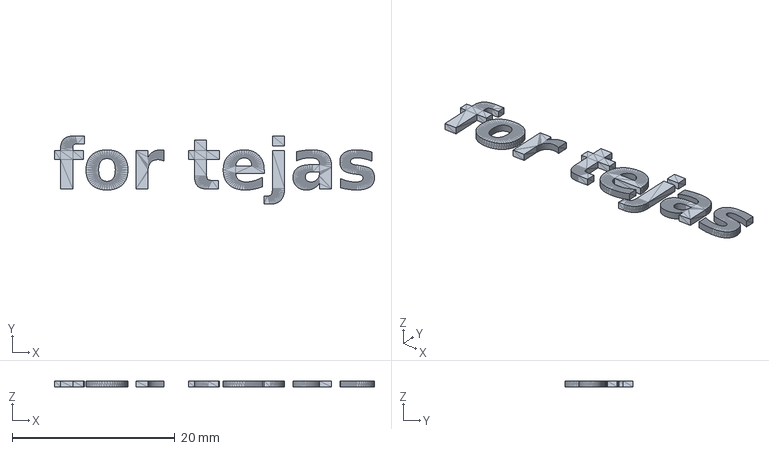
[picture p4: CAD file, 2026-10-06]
CAD/STEP/text.step
39.3 x 8.40 x 0.75 mm

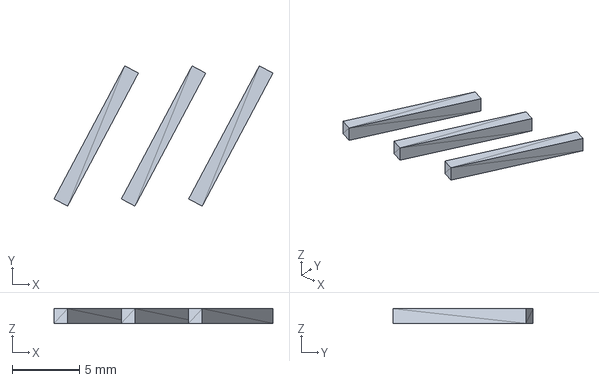
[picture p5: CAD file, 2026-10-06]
CAD/STEP/accents.step
16.3 x 10.4 x 1.10 mm

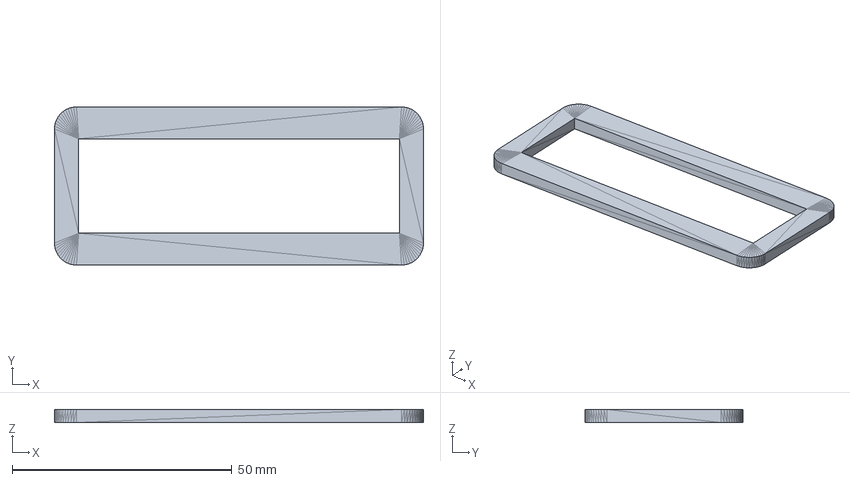
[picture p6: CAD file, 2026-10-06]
CAD/STEP/bezel.step
84.0 x 36.0 x 3.00 mm

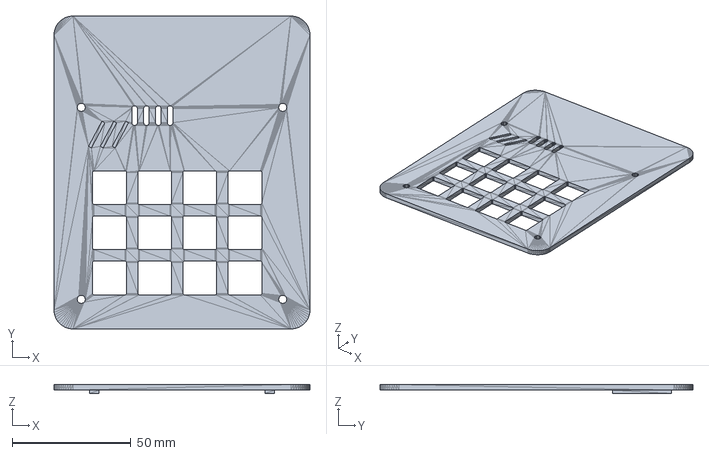
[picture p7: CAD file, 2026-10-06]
CAD/STEP/top.step
108.0 x 132.0 x 3.80 mm

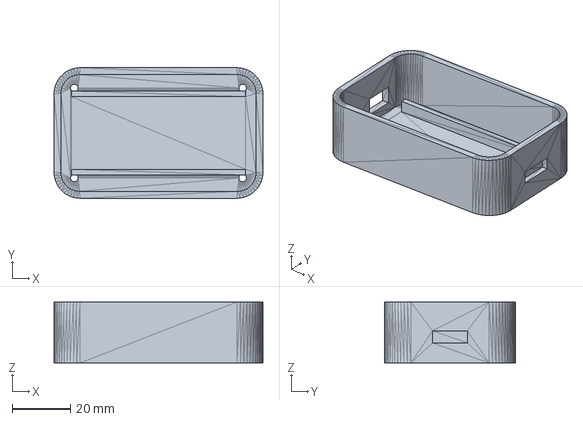
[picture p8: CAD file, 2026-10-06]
CAD/STEP/battery_pod.step
72.0 x 45.0 x 21.0 mm

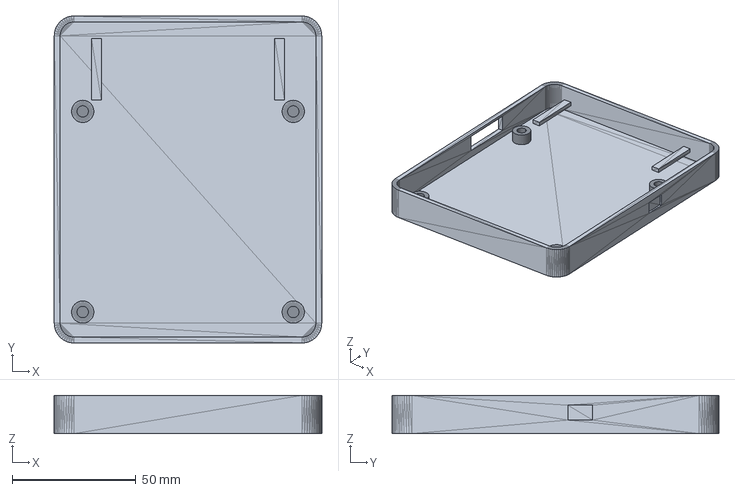
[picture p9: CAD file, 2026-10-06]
CAD/STEP/base.step
108.0 x 132.0 x 15.5 mm

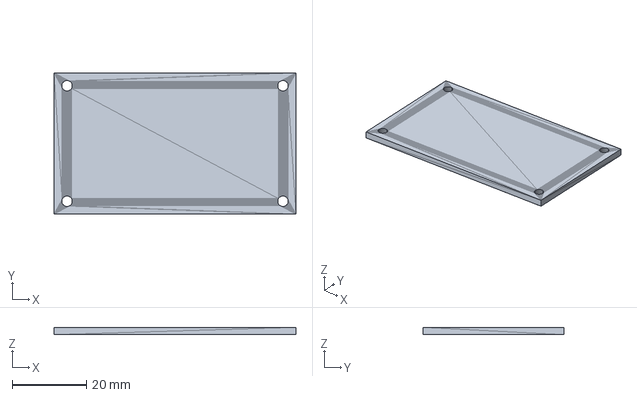
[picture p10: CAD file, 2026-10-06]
CAD/STEP/battery_door.step
65.0 x 38.0 x 2.00 mm

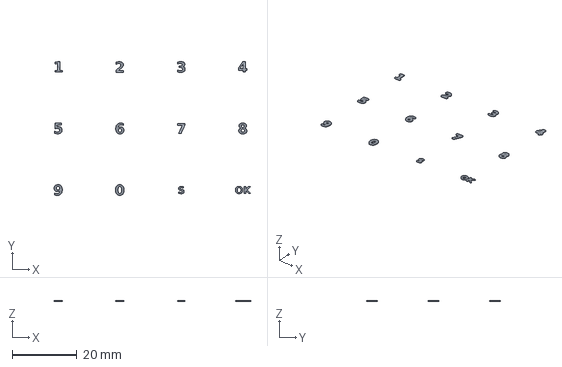
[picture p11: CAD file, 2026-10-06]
CAD/STEP/key_labels.step
61.0 x 41.5 x 0.38 mm

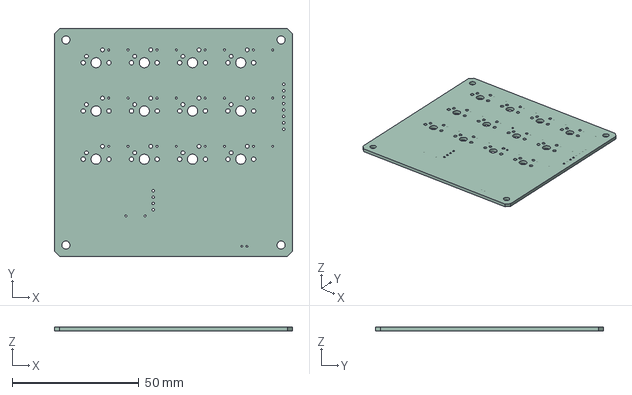
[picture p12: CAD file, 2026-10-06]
CAD/STEP/DawnKey_PCB.step
94.0 x 90.0 x 1.60 mm

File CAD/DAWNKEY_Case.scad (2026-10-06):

// DAWNKEY — parametric BLARE enclosure, designed around a 94 x 90 mm PCB.
// Units: mm. Print parts separately; verify the actual TFT, holder and switch before final print.
$fn = 48;
part = "assembly"; // base, top, bezel, battery_pod, battery_door, accents, text, assembly

// Main electronics envelope
PCB_X = 7.0;
PCB_Y = 8.0;
PCB_W = 94.0;
PCB_H = 90.0;
CASE_W = 108.0;
CASE_D = 132.0;
BASE_H = 15.5;
TOP_T = 2.4;
WALL = 2.4;
FLOOR = 2.4;
PCB_BOTTOM = 7.8;
PLATE_Z = BASE_H;

module round_slab(w,d,h,r,z=0) {
  translate([w/2,d/2,z])
    linear_extrude(height=h)
      offset(r=r) square([w-2*r,d-2*r], center=true);
}

module board_hole(x,y) {
  translate([PCB_X+x, PCB_Y+y, -0.2]) cylinder(d=3.4,h=22);
}

module pcb_posts() {
  for (p=[[4.5,4.5],[89.5,4.5],[4.5,85.5],[89.5,85.5]]) {
    translate([PCB_X+p[0], PCB_Y+p[1], FLOOR])
      difference() {
        cylinder(d=9.0,h=PCB_BOTTOM-FLOOR);
        // M3 heat-set insert pocket, open at the post top; confirm insert dimensions.
        translate([0,0,PCB_BOTTOM-FLOOR-4.8]) cylinder(d=4.6,h=5.1);
      }
  }
}

module base_shell() {
  difference() {
    round_slab(CASE_W,CASE_D,BASE_H,8.0,0);
    translate([WALL,WALL,FLOOR])
      round_slab(CASE_W-2*WALL,CASE_D-2*WALL,BASE_H-FLOOR+0.3,5.6,0);
    // Large USB/service clearance at the XIAO side. Final slot position depends on
    // the actual XIAO USB-C orientation and is intentionally generous for prototype fit.
    translate([-0.3, PCB_Y+57, 6.2]) cube([WALL+0.6,25,8.0]);
    // Pass-through from AA pod to PCB battery input harness.
    translate([CASE_W-1.0,71,5.5]) cube([3.0,10,6.0]);
  }
  pcb_posts();
  // Short internal rails support the TFT module below its top bezel.
  for (x=[15,89]) {
    translate([x,98.0,11.0]) cube([4.0,25.0,2.0]);
  }
}

module top_plate() {
  difference() {
    round_slab(CASE_W,CASE_D,TOP_T,8.0,PLATE_Z);
    // Four PCB M3 screws share the board mounting pattern and thread into insert posts.
    for (p=[[4.5,4.5],[89.5,4.5],[4.5,85.5],[89.5,85.5]])
      translate([PCB_X+p[0],PCB_Y+p[1],PLATE_Z-0.2]) cylinder(d=3.4,h=TOP_T+0.5);
    // MX plate apertures: nominal 14 mm; 0.2 mm clearance built in.
    for (x=[16.425,35.475,54.525,73.575])
      for (y=[13.5,32.55,51.6])
        translate([PCB_X+x,PCB_Y+y,PLATE_Z-0.2])
          linear_extrude(height=TOP_T+0.5)
            offset(r=0.6) square([13.0,13.0],center=true);
    // ST7789 visible window and underside pocket for its 76 x 28.4 mm PCB.
    translate([54,114,PLATE_Z-0.2]) cube([72,20.5,TOP_T+0.5],center=true);
    translate([54,114,PLATE_Z-0.1]) cube([77.0,29.4,1.25],center=true);
    // Acoustic vent array over the piezo area.
    for (x=[34,39,44,49])
      translate([x,90,PLATE_Z-0.2]) hull() {
        translate([0,-3,0]) cylinder(d=2.3,h=TOP_T+0.5);
        translate([0, 3,0]) cylinder(d=2.3,h=TOP_T+0.5);
      }
    // Two angled cyber-deck accent slots, filled with separate neon parts.
    for (x=[18,23,28])
      translate([x,82,PLATE_Z+TOP_T-0.75]) rotate([0,0,-28]) cube([1.4,12,1.7],center=true);
  }
  // Short display shelf lips capture the display PCB from behind; tune to the real module.
  for (x=[15,89])
    translate([x,98.0,PLATE_Z-1.4]) cube([4.0,25.0,1.5]);
}

module display_bezel() {
  // Raised octagonal visor, separate print; an internal shelf keeps the panel behind the aperture.
  difference() {
    translate([12,96,0]) round_slab(84,36,3.0,5.0,PLATE_Z+TOP_T-0.2);
    translate([54,114,PLATE_Z+TOP_T+1.3]) cube([73.0,21.5,4.6],center=true);
  }
}

// Sidecar pod gives a standard wired 2xAA holder a separate, serviceable compartment.
// Nominal cavity 66 x 37 x 19 mm. Measure the purchased holder before printing.
POD_X=110;
POD_Y=54;
POD_W=72;
POD_D=45;
POD_H=21;

module battery_pod() {
  difference() {
    round_slab(POD_W,POD_D,POD_H,9.0,0);
    translate([WALL,WALL,2.2])
      round_slab(POD_W-2*WALL,POD_D-2*WALL,POD_H-1.4,6.4,0);
    // Removable door opening; four M2.5 screw holes retain the cover.
    translate([POD_W/2,POD_D/2,-0.2]) cube([POD_W-6,POD_D-6,3.0],center=true);
    for (p=[[7,7],[POD_W-7,7],[7,POD_D-7],[POD_W-7,POD_D-7]])
      translate([p[0],p[1],-0.2]) cylinder(d=2.6,h=4.0);
    // Generic side-slot for an SPST slide switch in the holder-positive lead.
    translate([POD_W-0.5,POD_D/2,9.0]) cube([3.0,12.0,4.2],center=true);
    // Lead exit towards the main case.
    translate([-0.5,POD_D/2,5.5]) cube([3.0,10.0,6.0]);
  }
  // Internal ledges support a standard commercial two-cell holder.
  for (y=[8,POD_D-10])
    translate([6,y,2.2]) cube([POD_W-12,2.0,4.0]);
}

module battery_door() {
  translate([POD_X+POD_W/2,POD_Y+POD_D/2,0])
    difference() {
      cube([POD_W-7,POD_D-7,2.0],center=true);
      for (p=[[7,7],[POD_W-7,7],[7,POD_D-7],[POD_W-7,POD_D-7]])
        translate([p[0]-POD_W/2,p[1]-POD_D/2,-1.2]) cylinder(d=2.8,h=3.0);
    }
}

module neon_accents() {
  // Three flush-inlay slashes at the top-left edge of the name panel.
  for (i=[0:2])
    translate([18+i*5,82,PLATE_Z+TOP_T-1.35]) rotate([0,0,-28])
      cube([1.15,11.2,1.1],center=true);
}

module for_tejas() {
  // Separate black multi-material insert; print flat and place on the panel.
  translate([54,83.5,PLATE_Z+TOP_T-0.12])
    linear_extrude(height=0.75)
      text("for tejas",size=6.2,font="DejaVu Sans:style=Bold",halign="center",valign="center");
}

module key_labels() {
  labels=["1","2","3","4","5","6","7","8","9","0","S","OK"];
  xx=[16.425,35.475,54.525,73.575]; yy=[51.6,32.55,13.5];
  for (i=[0:11]) {
    c=i%4; r=floor(i/4); sz=(i<10)?3.2:2.2;
    translate([PCB_X+xx[c],PCB_Y+yy[r],PCB_BOTTOM+1.6+6.5+7.02])
      linear_extrude(height=0.38)
        text(labels[i],size=sz,font="DejaVu Sans:style=Bold",halign="center",valign="center");
  }
}

module display_graphics() {
  color("#111723") translate([18,103.75,PLATE_Z+TOP_T+0.02]) cube([72,20.5,0.25]);
  color("#10e6ec") translate([29,109,PLATE_Z+TOP_T+0.27])
    linear_extrude(height=0.16) text("07:00",size=8,font="DejaVu Sans:style=Bold");
  color("#ff4fb3") translate([67,113,PLATE_Z+TOP_T+0.27])
    linear_extrude(height=0.16) text("WAKE",size=2.5,font="DejaVu Sans:style=Bold");
}

module mock_components() {
  // Visual-only assembly stand-ins (not electrical footprints): PCB, keycaps, TFT and AA cells.
  color("#145b68") translate([PCB_X,PCB_Y,PCB_BOTTOM]) cube([PCB_W,PCB_H,1.6]);
  for (x=[16.425,35.475,54.525,73.575]) for (y=[13.5,32.55,51.6]) {
    color("#252525") translate([PCB_X+x-6.5,PCB_Y+y-6.5,PCB_BOTTOM+1.6]) cube([13,13,5]);
    color("#f5f1ed") translate([PCB_X+x-8.5,PCB_Y+y-8.5,PCB_BOTTOM+6.5]) cube([17,17,7]);
  }
  // TFT mock-up sits in the underside pocket; glass and sample glyphs show through the window.
  color("#171923") translate([16,99.8,PLATE_Z-0.7]) cube([76,28.4,1.2]);
  for (y=[POD_Y+12,POD_Y+33])
    color("#d3d4d8") translate([POD_X+36,y,8.5]) rotate([0,90,0]) cylinder(d=14.5,h=49,center=true);
}

module assembly() {
  color("#e9edf2") base_shell();
  color("#f7f7f4") top_plate();
  color("#191b22") display_bezel();
  color("#272934") translate([POD_X,POD_Y,0]) battery_pod();
  color("#25262b") battery_door();
  color("#11d9e8") neon_accents();
  color("#050505") for_tejas();
  mock_components();
  color("#050505") key_labels();
  display_graphics();
}

if (part=="base") color("#e9edf2") base_shell();
else if (part=="top") color("#f7f7f4") top_plate();
else if (part=="bezel") color("#191b22") display_bezel();
else if (part=="battery_pod") color("#272934") translate([POD_X,POD_Y,0]) battery_pod();
else if (part=="battery_door") color("#25262b") battery_door();
else if (part=="accents") color("#11d9e8") neon_accents();
else if (part=="text") color("#050505") for_tejas();
else if (part=="key_labels") color("#050505") key_labels();
else assembly();

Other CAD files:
CAD/STL/accents.stl
CAD/STL/base.stl
CAD/STL/battery_door.stl
CAD/STL/battery_pod.stl
CAD/STL/bezel.stl
CAD/STL/key_labels.stl
CAD/STL/text.stl
CAD/STL/top.stl

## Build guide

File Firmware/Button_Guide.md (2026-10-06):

# DAWNKEY button guide

The twelve MX switches are arranged **4 columns × 3 rows**, viewed from the front. Read left-to-right, top-to-bottom:

| Physical key | Label | Normal clock view | Setting mode | When the alarm is ringing |
|---|---:|---|---|---|
| SW01 | `1` | No action | Enters digit 1 | Enters digit 1 of the wake code |
| SW02 | `2` | No action | Enters digit 2 | Enters digit 2 of the wake code |
| SW03 | `3` | No action | Enters digit 3 | Enters digit 3 of the wake code |
| SW04 | `4` | No action | Enters digit 4 | Enters digit 4 of the wake code |
| SW05 | `5` | No action | Enters digit 5 | Enters digit 5 of the wake code |
| SW06 | `6` | No action | Enters digit 6 | Enters digit 6 of the wake code |
| SW07 | `7` | No action | Enters digit 7 | Enters digit 7 of the wake code |
| SW08 | `8` | No action | Enters digit 8 | Enters digit 8 of the wake code |
| SW09 | `9` | No action | Enters digit 9 | Enters digit 9 of the wake code |
| SW10 | `0` | No action | Enters digit 0 | Enters digit 0 of the wake code |
| SW11 | `SNOOZE` | Short press changes the display page; hold ~0.85 s to set the RTC clock (`HHMM`) | Short press clears the current entry | Short press snoozes for 5 minutes; hold is not a snooze shortcut |
| SW12 | `STOP/OK` | Short press toggles alarm on/off; hold ~0.85 s to set the alarm time (`HHMM`) | Saves a valid four-digit `HHMM` entry | Checks the four-digit dismiss code and stops the alarm only if correct |

## Wake challenge

The starter sketch uses **3141** as the example alarm-dismiss code. Change `DISMISS_CODE` near the top of `DAWNKEY.ino` if you want another code, then upload the sketch again. During ringing, enter four digits using SW01–SW10, then press SW12. An incorrect code clears the entry and the alarm continues. SW11 gives one 5-minute snooze.

## Setting the clock and alarm

- Hold **SW11** for about 0.85 seconds, enter four digits as 24-hour `HHMM`, then press **SW12** to set the current clock time. The date is retained from the RTC; if the RTC has lost power, its date is initialized from the firmware compile timestamp.
- Hold **SW12** for about 0.85 seconds, enter the new alarm `HHMM`, then press **SW12** to save and enable it.
- In either setting mode, press **SW11** to clear the partially typed value. Values outside `00:00`–`23:59` are rejected.
- The default alarm is **07:00 and enabled**. A short press of SW12 toggles it.

The screen/backlight is always on in this starter firmware. It avoids Wi-Fi to reduce power draw, but no battery-runtime claim has been measured.

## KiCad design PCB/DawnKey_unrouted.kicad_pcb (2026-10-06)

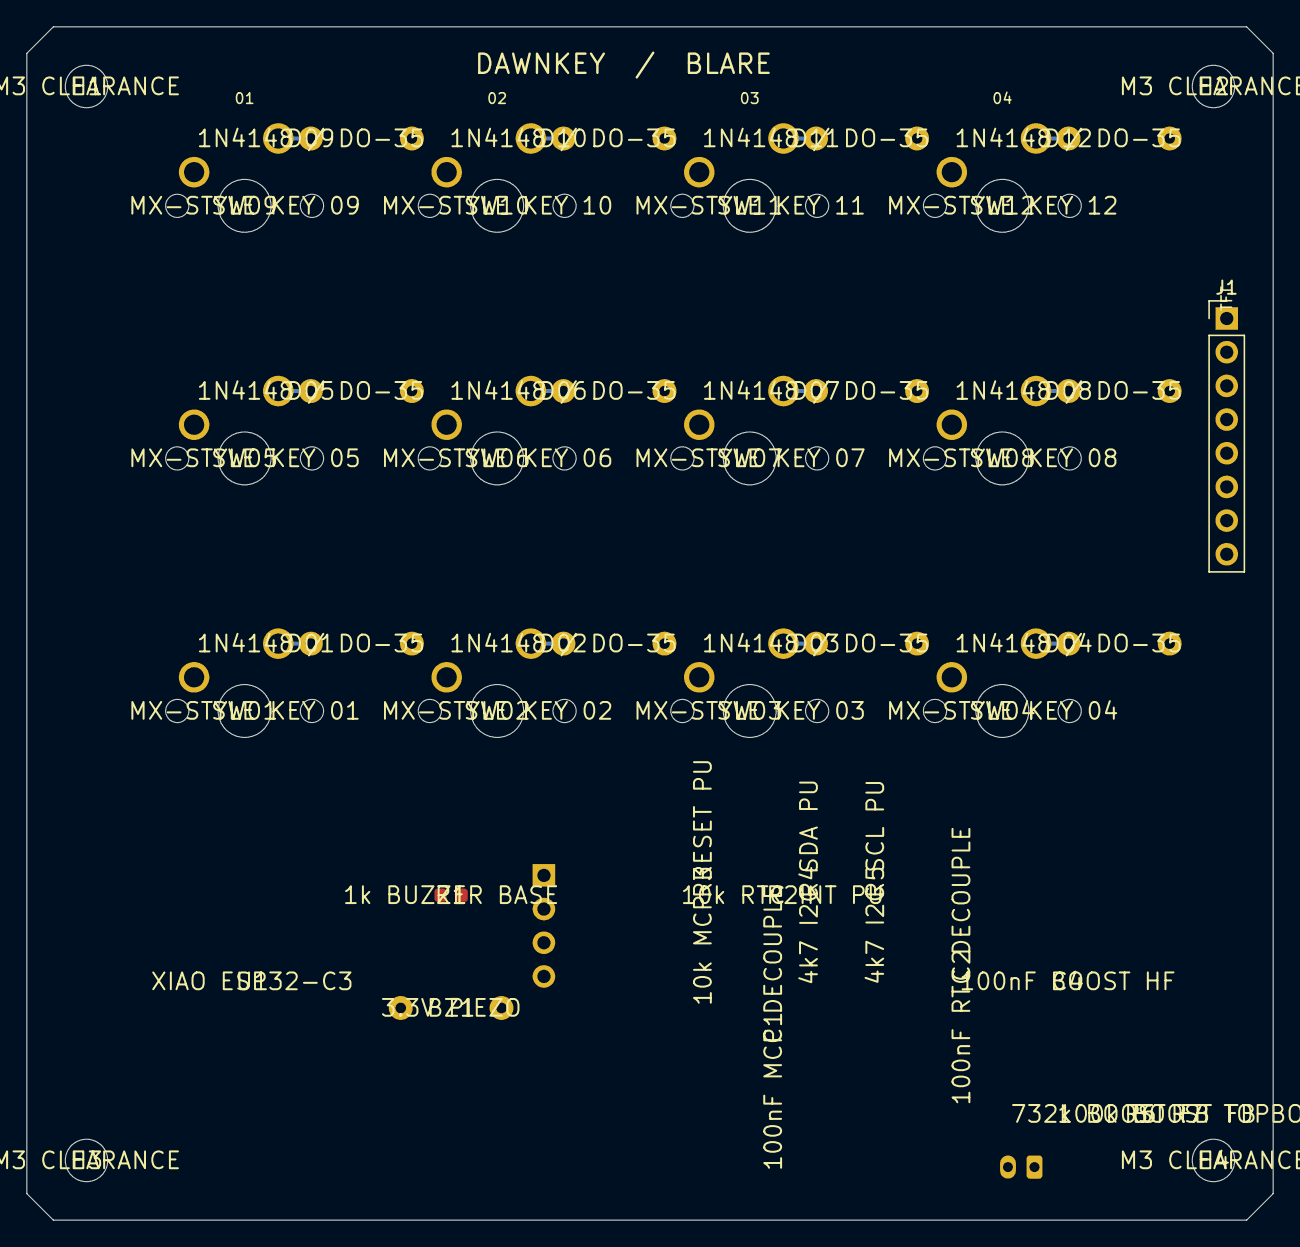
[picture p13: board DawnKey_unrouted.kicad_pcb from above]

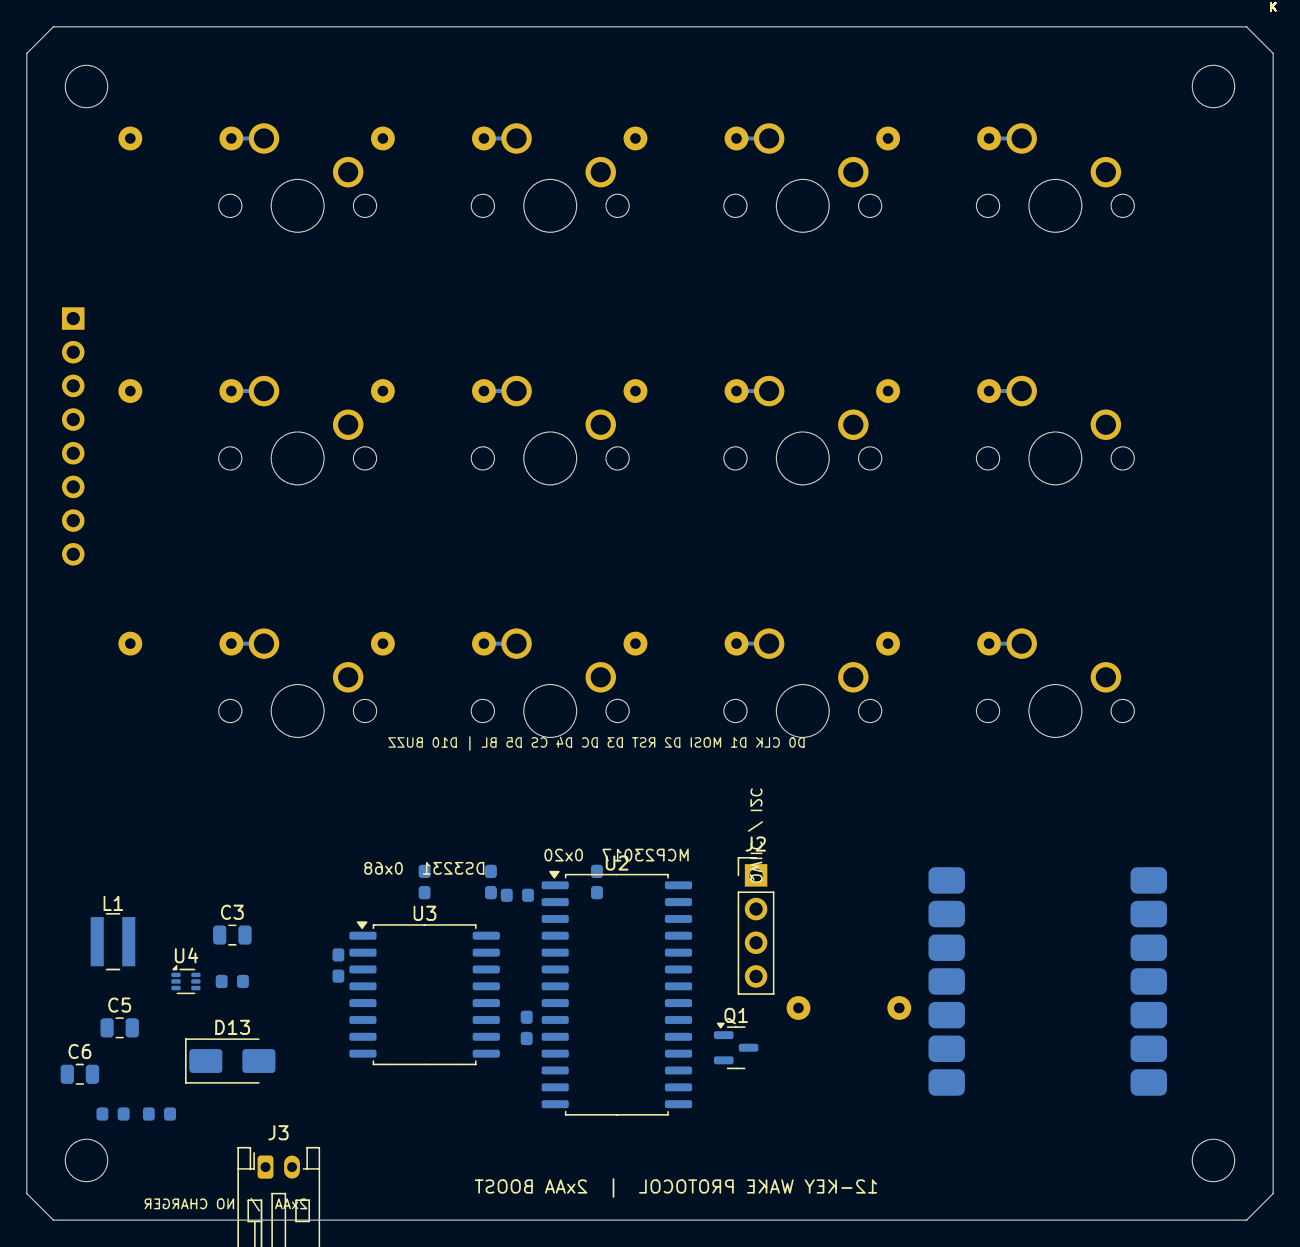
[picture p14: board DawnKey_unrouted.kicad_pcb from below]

Board: 2 copper layers, 94.0 x 90.0 mm, 52 parts (34 on the bottom side), 39 nets.

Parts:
BZ1: 3.3V PIEZO; Buzzer_12x9.5RM7.6
C1: 100nF MCP DECOUPLE; C_0603_1608Metric
C2: 100nF RTC DECOUPLE; C_0603_1608Metric
C3: 10uF 10V X7R IN; C_0805_2012Metric
C4: 100nF BOOST HF; C_0603_1608Metric
C5, C6: 22uF 10V X7R OUT; C_0805_2012Metric
D01, D02, D03, D04, D05, D06, D07, D08, D09, D10, D11, D12: 1N4148 / DO-35; D_DO-35_SOD27_P7.62mm_Horizontal
D13: SS14 1A SCHOTTKY; D_SMA
H1, H2, H3, H4: M3 CLEARANCE; MountingHole_3.2mm_M3
J1: TFT / ST7789; PinHeader_1x08_P2.54mm_Vertical
J2: I2C EXPANSION: 3V3 GND SDA SCL; PinHeader_1x04_P2.54mm_Vertical
J3: 2xAA PACK (SWITCHED); JST_PH_S2B-PH-K_1x02_P2.00mm_Horizontal
L1: 1uH Isat>=7A; L_Wuerth_MAPI-4030
Q1: MMBT3904 / NPN; SOT-23
R1: 1k BUZZER BASE; R_0603_1608Metric
R2: 10k RTC INT PU; R_0603_1608Metric
R3: 10k MCP RESET PU; R_0603_1608Metric
R4: 4k7 I2C SDA PU; R_0603_1608Metric
R5: 4k7 I2C SCL PU; R_0603_1608Metric
R6: 732k BOOST FB TOP; R_0603_1608Metric
R7: 100k BOOST FB BOT; R_0603_1608Metric
SW01: MX-STYLE KEY 01; SW_MX_1u
SW02: MX-STYLE KEY 02; SW_MX_1u
SW03: MX-STYLE KEY 03; SW_MX_1u
SW04: MX-STYLE KEY 04; SW_MX_1u
SW05: MX-STYLE KEY 05; SW_MX_1u
SW06: MX-STYLE KEY 06; SW_MX_1u
SW07: MX-STYLE KEY 07; SW_MX_1u
SW08: MX-STYLE KEY 08; SW_MX_1u
SW09: MX-STYLE KEY 09; SW_MX_1u
SW10: MX-STYLE KEY 10; SW_MX_1u
SW11: MX-STYLE KEY 11; SW_MX_1u
SW12: MX-STYLE KEY 12; SW_MX_1u
U1: XIAO ESP32-C3; XIAO-ESP32-C3-SMD
U2: MCP23017-I/SO; SOIC-28W_7.5x17.9mm_P1.27mm
U3: DS3231S RTC; SOIC-16W_7.5x10.3mm_P1.27mm
U4: TPS61023 2xAA BOOST; SOT-563

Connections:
3V3: BZ1.1, C1.1, C2.1, J1.2, J2.1, R2.2, R3.1, R4.1, R5.1, U1.12, U2.9, U3.2
BAT_RAW: C3.1, C4.1, J3.1, L1.1, U4.2, U4.3
BOOST_5V: C5.1, C6.1, D13.2, R6.1, U4.6
BOOST_FB: R6.2, R7.1, U4.1
BOOST_SW: L1.2, U4.5
BUZZER: BZ1.2, Q1.3
BUZZER_CTL: R1.1, U1.11
BUZZER_SW: Q1.1, R1.2
GND: C1.2, C2.2, C3.2, C4.2, C5.2, C6.2, J1.1, J2.2, J3.2, Q1.2, R7.2, U1.13, U2.10, U2.15, U2.16, U2.17, U3.5, U3.6, U3.7, U3.8, U3.9, U3.10, U3.11, U3.12, U3.13, U3.14, U4.4
I2C_SCL: J2.4, R5.2, U1.7, U2.12, U3.16
I2C_SDA: J2.3, R4.2, U1.8, U2.13, U3.15
KEY_COL0: SW01.1, SW05.1, SW09.1, U2.1
KEY_COL1: SW02.1, SW06.1, SW10.1, U2.2
KEY_COL2: SW03.1, SW07.1, SW11.1, U2.3
KEY_COL3: SW04.1, SW08.1, SW12.1, U2.4
KEY_ROW0: D01.2, D02.2, D03.2, D04.2, U2.5
KEY_ROW1: D05.2, D06.2, D07.2, D08.2, U2.6
KEY_ROW2: D09.2, D10.2, D11.2, D12.2, U2.7
KINT01: D01.1, SW01.2
KINT02: D02.1, SW02.2
KINT03: D03.1, SW03.2
KINT04: D04.1, SW04.2
KINT05: D05.1, SW05.2
KINT06: D06.1, SW06.2
KINT07: D07.1, SW07.2
KINT08: D08.1, SW08.2
KINT09: D09.1, SW09.2
KINT10: D10.1, SW10.2
KINT11: D11.1, SW11.2
KINT12: D12.1, SW12.2
MCP_RESET: R3.2, U2.18
RTC_INT: R2.1, U3.3
TFT_BL: J1.8, U1.6
TFT_CS: J1.7, U1.5
TFT_DC: J1.6, U1.4
TFT_MOSI: J1.4, U1.2
TFT_RST: J1.5, U1.3
TFT_SCLK: J1.3, U1.1
USB_5V: D13.1, U1.14

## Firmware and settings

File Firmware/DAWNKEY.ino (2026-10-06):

/*
  DAWNKEY — BLARE alarm clock firmware
  Board: Seeed XIAO ESP32-C3 + MCP23017 (0x20) + DS3231 (0x68)
  Screen: ST7789 76x284, BL active-low
  Key matrix: MCP GPA0..3 = columns; GPA4..6 = rows; 1N4148 diodes
  Power: two AA cells -> TPS61023 5V boost -> series Schottky -> XIAO 5V

  Install Arduino libraries:
    Adafruit GFX Library
    Adafruit ST7735 and ST7789 Library
    Adafruit MCP23017 Arduino Library
    RTClib by Adafruit
*/
#include <Wire.h>
#include <SPI.h>
#include <Adafruit_GFX.h>
#include <Adafruit_ST7789.h>
#include <Adafruit_MCP23X17.h>
#include <RTClib.h>
#include <Preferences.h>

// BLARE firmware guide pin assignments for the display.
#define TFT_SCLK 0
#define TFT_MOSI 1
#define TFT_RST  2
#define TFT_DC   3
#define TFT_CS   4
#define TFT_BL   5
// Main PCB routes the transistor buzzer control to XIAO D10 (GPIO10),
// deliberately avoiding the GPIO8/GPIO9 boot-strapping pins.
#define BUZZER_PIN D10
// I2C uses the XIAO pads routed to D7 (SDA) and D6 (SCL), not the TFT pins.
#define I2C_SDA_PIN D7
#define I2C_SCL_PIN D6

class DawnKeyST7789 : public Adafruit_ST7789 {
 public:
  DawnKeyST7789(int8_t cs, int8_t dc, int8_t mosi, int8_t sclk, int8_t rst)
      : Adafruit_ST7789(cs, dc, mosi, sclk, rst) {}
  void setOffsets(uint8_t col, uint8_t row) {
    _colstart = _colstart2 = col;
    _rowstart = _rowstart2 = row;
  }
};

DawnKeyST7789 tft(TFT_CS, TFT_DC, TFT_MOSI, TFT_SCLK, TFT_RST);
Adafruit_MCP23X17 mcp;
RTC_DS3231 rtc;
Preferences prefs;

constexpr uint8_t MCP_ADDR = 0x20;
constexpr uint8_t COLS[4] = {0, 1, 2, 3};
constexpr uint8_t ROWS[3] = {4, 5, 6};
constexpr uint32_t DEBOUNCE_MS = 28;
constexpr uint32_t LONG_PRESS_MS = 850;
constexpr uint32_t SNOOZE_SECONDS = 5 * 60;
const char *DISMISS_CODE = "3141";  // Change this in code if desired.
const char *KEYS[12] = {"1", "2", "3", "4", "5", "6", "7", "8", "9", "0", "SNOOZE", "STOP/OK"};

enum UiMode : uint8_t { NORMAL, SET_ALARM, SET_CLOCK, RINGING };
UiMode mode = NORMAL;

bool rawState[12] = {};
bool stableState[12] = {};
uint32_t rawChangedAt[12] = {};
uint32_t keyDownAt[12] = {};
uint8_t alarmHour = 7;
uint8_t alarmMinute = 0;
bool alarmEnabled = true;
uint8_t screenPage = 0;
String digits;
String alarmCode;
bool alarmHasTriggeredToday = false;
bool snoozeArmed = false;
uint32_t snoozeAt = 0;
uint32_t lastUiDraw = 0;
uint32_t lastAlarmCheck = 0;
uint32_t lastBeep = 0;
bool beepPhase = false;

String twoDigits(uint8_t n) { return (n < 10 ? "0" : "") + String(n); }

void drawNormal() {
  DateTime now = rtc.now();
  tft.fillScreen(ST77XX_BLACK);
  tft.setTextColor(ST77XX_CYAN, ST77XX_BLACK);
  tft.setTextSize(2);
  tft.setCursor(6, 5);
  tft.print("DAWNKEY");
  tft.setTextColor(ST77XX_WHITE, ST77XX_BLACK);
  tft.setTextSize(3);
  tft.setCursor(6, 28);
  tft.print(twoDigits(now.hour()) + ":" + twoDigits(now.minute()));
  tft.setTextSize(1);
  tft.setCursor(166, 9);
  tft.setTextColor(alarmEnabled ? ST77XX_GREEN : ST77XX_RED, ST77XX_BLACK);
  tft.print(alarmEnabled ? "ALARM ON" : "ALARM OFF");
  tft.setCursor(166, 26);
  tft.setTextColor(ST77XX_WHITE, ST77XX_BLACK);
  tft.print("WAKE " + twoDigits(alarmHour) + ":" + twoDigits(alarmMinute));
  tft.setCursor(166, 44);
  if (screenPage == 0) {
    tft.print("HOLD SNOOZE: SET TIME");
  } else {
    tft.print("HOLD STOP: SET ALARM");
  }
  tft.setCursor(6, 63);
  tft.setTextColor(ST77XX_YELLOW, ST77XX_BLACK);
  tft.print("11 SNOOZE / 12 STOP");
}

void drawEntry(const char *title) {
  tft.fillScreen(ST77XX_BLACK);
  tft.setTextColor(ST77XX_MAGENTA, ST77XX_BLACK);
  tft.setTextSize(2);
  tft.setCursor(8, 7);
  tft.print(title);
  tft.setTextColor(ST77XX_WHITE, ST77XX_BLACK);
  tft.setTextSize(3);
  tft.setCursor(8, 37);
  String shown = digits;
  while (shown.length() < 4) shown += "_";
  tft.print(shown.substring(0, 2) + ":" + shown.substring(2, 4));
  tft.setTextSize(1);
  tft.setCursor(170, 49);
  tft.print("1-0 type  HHMM");
  tft.setCursor(170, 63);
  tft.print("12 save  11 clear");
}

void drawRinging() {
  tft.fillScreen(ST77XX_BLACK);
  tft.setTextColor(ST77XX_RED, ST77XX_BLACK);
  tft.setTextSize(3);
  tft.setCursor(12, 6);
  tft.print("WAKE UP!");
  tft.setTextColor(ST77XX_WHITE, ST77XX_BLACK);
  tft.setTextSize(2);
  tft.setCursor(12, 39);
  tft.print("CODE: ");
  for (uint8_t i = 0; i < alarmCode.length(); ++i) tft.print("*");
  for (uint8_t i = alarmCode.length(); i < 4; ++i) tft.print("_");
  tft.setTextSize(1);
  tft.setCursor(12, 66);
  tft.print("11 snoozes 5m | enter 3141 then 12");
}

void drawUi() {
  if (mode == NORMAL) drawNormal();
  else if (mode == SET_ALARM) drawEntry("SET ALARM");
  else if (mode == SET_CLOCK) drawEntry("SET CLOCK");
  else drawRinging();
}

void saveAlarm() {
  prefs.putUChar("ah", alarmHour);
  prefs.putUChar("am", alarmMinute);
  prefs.putBool("ae", alarmEnabled);
}

bool parseHHMM(uint8_t &hh, uint8_t &mm) {
  if (digits.length() != 4) return false;
  hh = digits.substring(0, 2).toInt();
  mm = digits.substring(2, 4).toInt();
  return hh < 24 && mm < 60;
}

void stopAlarm() {
  noTone(BUZZER_PIN);
  mode = NORMAL;
  snoozeArmed = false;
  alarmCode = "";
  alarmHasTriggeredToday = true;
  drawUi();
}

void startAlarm() {
  mode = RINGING;
  alarmCode = "";
  snoozeArmed = false;
  lastBeep = 0;
  drawUi();
}

void enterSetMode(UiMode target) {
  noTone(BUZZER_PIN);
  digits = "";
  mode = target;
  drawUi();
}

void appendDigit(uint8_t key) {
  const char *d = (key == 9) ? "0" : String(key + 1).c_str();
  if (digits.length() < 4) digits += d;
}

void onKey(uint8_t key, uint32_t heldMs) {
  if (key < 10) {
    const char *d = (key == 9) ? "0" : nullptr;
    if (mode == SET_ALARM || mode == SET_CLOCK) {
      if (key == 9) digits += "0";
      else digits += String(key + 1);
      if (digits.length() > 4) digits.remove(4);
      drawUi();
    } else if (mode == RINGING) {
      if (key == 9) alarmCode += "0";
      else alarmCode += String(key + 1);
      if (alarmCode.length() > 4) alarmCode.remove(4);
      drawUi();
    }
    (void)d;
    return;
  }

  if (key == 10) {  // Button 11: SNOOZE / CLOCK SET
    if (mode == RINGING) {
      noTone(BUZZER_PIN);
      mode = NORMAL;
      snoozeArmed = true;
      snoozeAt = rtc.now().unixtime() + SNOOZE_SECONDS;
      drawUi();
    } else if (mode == SET_ALARM || mode == SET_CLOCK) {
      digits = "";
      drawUi();
    } else if (heldMs >= LONG_PRESS_MS) {
      enterSetMode(SET_CLOCK);
    } else {
      screenPage ^= 1;
      drawUi();
    }
    return;
  }

  // Button 12: STOP / OK / ALARM SET
  if (mode == RINGING) {
    if (alarmCode == DISMISS_CODE) stopAlarm();
    else {
      alarmCode = "";
      drawUi();
    }
  } else if (mode == SET_ALARM || mode == SET_CLOCK) {
    uint8_t hh, mm;
    if (!parseHHMM(hh, mm)) {
      digits = "";
      drawUi();
      return;
    }
    if (mode == SET_ALARM) {
      alarmHour = hh;
      alarmMinute = mm;
      alarmEnabled = true;
      saveAlarm();
    } else {
      DateTime now = rtc.now();
      rtc.adjust(DateTime(now.year(), now.month(), now.day(), hh, mm, 0));
    }
    digits = "";
    mode = NORMAL;
    drawUi();
  } else if (heldMs >= LONG_PRESS_MS) {
    enterSetMode(SET_ALARM);
  } else {
    alarmEnabled = !alarmEnabled;
    saveAlarm();
    drawUi();
  }
}

void scanKeys() {
  uint32_t now = millis();
  for (uint8_t c = 0; c < 4; ++c) {
    mcp.pinMode(COLS[c], OUTPUT);
    mcp.digitalWrite(COLS[c], LOW);
    delayMicroseconds(40);
    for (uint8_t r = 0; r < 3; ++r) {
      uint8_t i = r * 4 + c;
      bool raw = (mcp.digitalRead(ROWS[r]) == LOW);
      if (raw != rawState[i]) {
        rawState[i] = raw;
        rawChangedAt[i] = now;
      }
      if ((now - rawChangedAt[i]) >= DEBOUNCE_MS && stableState[i] != rawState[i]) {
        stableState[i] = rawState[i];
        if (stableState[i]) keyDownAt[i] = now;
        else onKey(i, now - keyDownAt[i]);
      }
    }
    mcp.pinMode(COLS[c], INPUT_PULLUP);
  }
}

void checkAlarm() {
  DateTime now = rtc.now();
  if (snoozeArmed && now.unixtime() >= snoozeAt) {
    snoozeArmed = false;
    startAlarm();
  }
  if (!alarmEnabled || mode == RINGING || snoozeArmed) return;
  if (now.hour() == alarmHour && now.minute() == alarmMinute && now.second() == 0) {
    // Stop the alarm repeating every loop through the entire matching minute.
    if (!alarmHasTriggeredToday) {
      alarmHasTriggeredToday = true;
      startAlarm();
    }
  }
  if (now.hour() == 0 && now.minute() == 0 && now.second() == 1) {
    alarmHasTriggeredToday = false;
  }
}

void setup() {
  Serial.begin(115200);
  pinMode(TFT_BL, OUTPUT);
  digitalWrite(TFT_BL, LOW);  // BLARE TFT backlight is active-low.
  pinMode(BUZZER_PIN, OUTPUT);
  noTone(BUZZER_PIN);

  Wire.begin(I2C_SDA_PIN, I2C_SCL_PIN);
  if (!mcp.begin_I2C(MCP_ADDR, &Wire)) {
    Serial.println("ERROR: MCP23017 not found at 0x20");
  } else {
    for (uint8_t c = 0; c < 4; ++c) mcp.pinMode(COLS[c], INPUT_PULLUP);
    for (uint8_t r = 0; r < 3; ++r) mcp.pinMode(ROWS[r], INPUT_PULLUP);
  }

  if (!rtc.begin(&Wire)) Serial.println("ERROR: DS3231 not found at 0x68");
  else if (rtc.lostPower()) rtc.adjust(DateTime(F(__DATE__), F(__TIME__)));

  prefs.begin("dawnkey", false);
  alarmHour = prefs.getUChar("ah", 7);
  alarmMinute = prefs.getUChar("am", 0);
  alarmEnabled = prefs.getBool("ae", true);

  tft.init(76, 284);
  tft.setOffsets(82, 18);
  tft.invertDisplay(false);
  tft.setRotation(1);
  drawUi();
}

void loop() {
  scanKeys();
  uint32_t now = millis();
  if (now - lastAlarmCheck >= 200) {
    lastAlarmCheck = now;
    checkAlarm();
  }
  if (mode == RINGING && now - lastBeep >= 550) {
    lastBeep = now;
    beepPhase = !beepPhase;
    tone(BUZZER_PIN, beepPhase ? 2200 : 1650);
  }
  if (mode == NORMAL && now - lastUiDraw >= 1000) {
    lastUiDraw = now;
    drawUi();
  }
}

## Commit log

2026-10-06 Add DawnKey design and production files
    [BOM.csv, DAWNKEY_Case.scad, DAWNKEY_Case_Assembly.step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]
2026-10-06 Remove project files from main
    [BOM.csv, DAWNKEY_Case.scad, DAWNKEY_Case_Assembly.step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]
2026-10-06 Add CAD/DAWNKEY_Case.scad
    [DAWNKEY_Case.scad]
2026-10-06 Add CAD/README.md
2026-10-06 Add CAD/STEP/DAWNKEY_Case_Assembly.step
    [DAWNKEY_Case_Assembly.step]
2026-10-06 Add CAD/STEP/DawnKey_PCB.step
    [DawnKey_PCB.step]
2026-10-06 Add CAD/STEP/accents.step
    [accents.step]
2026-10-06 Add CAD/STEP/base.step
    [base.step]
2026-10-06 Add CAD/STEP/battery_door.step
    [battery_door.step]
2026-10-06 Add CAD/STEP/battery_pod.step
    [battery_pod.step]
2026-10-06 Add CAD/STEP/bezel.step
    [bezel.step]
2026-10-06 Add CAD/STEP/key_labels.step
    [key_labels.step]
2026-10-06 Add CAD/STEP/text.step
    [text.step]
2026-10-06 Add CAD/STEP/top.step
    [top.step]
2026-10-06 Add CAD/STL/accents.stl
    [accents.stl]
2026-10-06 Add CAD/STL/base.stl
    [base.stl]
2026-10-06 Add CAD/STL/battery_door.stl
    [battery_door.stl]
2026-10-06 Add CAD/STL/battery_pod.stl
    [battery_pod.stl]
2026-10-06 Add CAD/STL/bezel.stl
    [bezel.stl]
2026-10-06 Add CAD/STL/key_labels.stl
    [key_labels.stl]
2026-10-06 Add CAD/STL/text.stl
    [text.stl]
2026-10-06 Add CAD/STL/top.stl
    [top.stl]
2026-10-06 Add CAD/stl_to_step.FCMacro
2026-10-06 Add Docs/Power_and_IO.md
2026-10-06 Add Firmware/Button_Guide.md
2026-10-06 Add PCB/BOM.csv
    [BOM.csv]
2026-10-06 Add PCB/DawnKey.dsn
    [DawnKey.dsn]
2026-10-06 Add PCB/DawnKey.kicad_pcb
    [DawnKey.kicad_pcb]
2026-10-06 Add PCB/DawnKey.kicad_pro
2026-10-06 Add PCB/DawnKey.ses
2026-10-06 Add PCB/DawnKey_unrouted.kicad_pcb
    [DawnKey_unrouted.kicad_pcb]
2026-10-06 Add PCB/generate.py
2026-10-06 Add PCB/import_routes.py
2026-10-06 Add PCB/route.log
2026-10-06 Add Production/Gerbers.zip
2026-10-06 Add Production/Gerbers/DawnKey-B_Cu.gbl
    [DawnKey-B_Cu.gbl]
2026-10-06 Add Production/Gerbers/DawnKey-B_Mask.gbs
    [DawnKey-B_Mask.gbs]
2026-10-06 Add Production/Gerbers/DawnKey-B_Silkscreen.gbo
    [DawnKey-B_Silkscreen.gbo]
2026-10-06 Add Production/Gerbers/DawnKey-Edge_Cuts.gm1
    [DawnKey-Edge_Cuts.gm1]
2026-10-06 Add Production/Gerbers/DawnKey-F_Cu.gtl
    [DawnKey-F_Cu.gtl]
2026-10-06 Add Production/Gerbers/DawnKey-F_Mask.gts
    [DawnKey-F_Mask.gts]
2026-10-06 Add Production/Gerbers/DawnKey-F_Silkscreen.gto
    [DawnKey-F_Silkscreen.gto]
2026-10-06 Add Production/Gerbers/DawnKey-NPTH-drl_map.svg
2026-10-06 Add Production/Gerbers/DawnKey-NPTH.drl
    [DawnKey-NPTH.drl]
2026-10-06 Add Production/Gerbers/DawnKey-PTH-drl_map.svg
2026-10-06 Add Production/Gerbers/DawnKey-PTH.drl
    [DawnKey-PTH.drl]
2026-10-06 Add Production/Gerbers/DawnKey-job.gbrjob
    [DawnKey-job.gbrjob]
2026-10-06 Add Production/Gerbers/README.txt
2026-10-06 Add Production/pad_net_map.csv
    [pad_net_map.csv]
2026-10-06 Add Production/placements.csv
    [placements.csv]
2026-10-06 Update README with gallery and prototype status
    Added a gallery section with images and updated prototype status information.
